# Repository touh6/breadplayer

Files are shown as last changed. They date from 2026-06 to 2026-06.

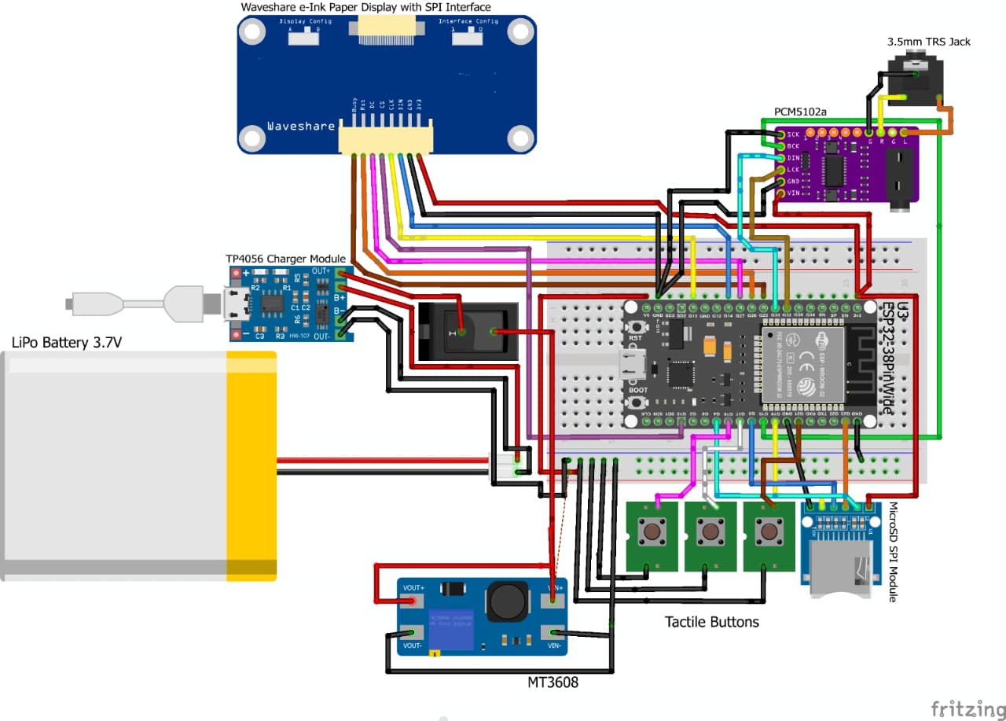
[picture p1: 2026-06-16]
images/wiring diagram.jpeg

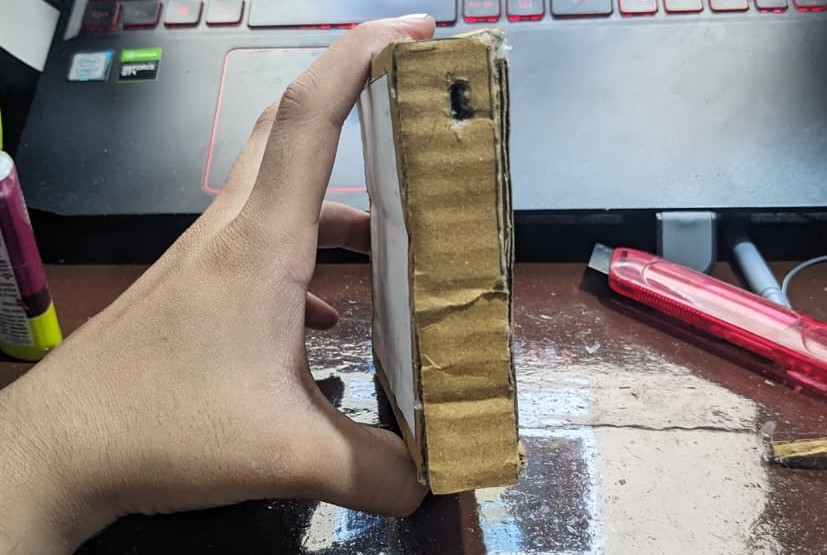
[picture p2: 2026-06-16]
images/left cbd.jpeg

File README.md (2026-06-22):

# breadplayer
full ds
a cassette player styled mp3 player with an e-ink display that shows album art when music is played.

## about the project:
this is an mp3 player with a 3d printed enclosure that is shaped like a cassette player. the heart of this device is the esp32-wroom microcontroller. other components include a waveshare 4.2'' e-Ink display, tactile buttons, pcm5102a, mt3608 booster, 3.5mm trs jack, microsd module with spi interface, tp4056 charging module, kcd11 spst switch and a 3.7v Li-Po battery. 

i wanted this to be in the shape of a cassette player as i've forever been enamored by retro tech. i absolutely love music; it is an integral part of me and i've always correlated them with my memories. so, this is special to me. 

i have a hard time visualizing certain things so i made a 2d version on canva to understand how i could actually pull this off and once i did, i made a dummy version of the same using cardboard. 

## 2d version:
<table><tr>
  <td></td>
    <td></td>
   <td></td>
    <td></td>
</tr></table>

## cardboard edition:
<table><tr>
  <td></td>
    <td></td>
   <td></td>
    <td></td>
</tr></table>

<table><tr>
  <td></td>
    <td></td>
   <td></td>
    <td></td>
</tr></table>

i was quite happy with how the dummy version turned out. i ended up sticking with the same visuals and designed the whole thing on solidworks.

## to build your own breadplayer: 
firstly, buy all the components as mentioned in the [bill of materials](https://github.com/touh6/breadplayer/tree/main/bill%20of%20materials), use the perfboard and solder them using the wiring diagram/schematic. and then, you will need to 3d print the enclosure { files of which you can find in the [cad folder](https://github.com/touh6/breadplayer/tree/main/cad) }, flash the microcontroller with [firmware](https://github.com/touh6/breadplayer/tree/main/firmware) using VS Code with PlatoformIO and then, assemble it all in the case and you're good to go! :))

## schematic:
v9
built using kicad

## wiring diagram:
WhatsApp Image 2026-06-16 at 3 24 42 PM
built using fritzing

## construction:
<table><tr>
  <td></td>
    <td></td>
</tr></table>

<table><tr>
      <h2 align="center">front & back: </h2>
  <td></td>
    <td></td>
</tr></table>

<table><tr>
      <h2 align="center">top view & side view: </h2>
   <td></td>
    <td></td>
</tr></table>

## assembled:
full 3

## tools i used:
<ul style="list-style-type:none;">
    <li>schematics: <a href="https://www.kicad.org">kicad</a></li>
    <li>cad: <a href="https://www.solidworks.com">solidworks</a></li>
    <li>wiring diagram: <a href="https://fritzing.org/">fritzing</a></li>
    <li>zine: <a href="https://www.canva.com">canva</a></li>
</ul>

## bill of materials: 
|name |quantity  |cost|link|
|---|---|---|-----|
|1) ESP32-WROOM-32 | 1|  $3.58 |[link](https://robu.in/product/esp-wroom-32-esp32-wifi-bt-ble-mcu-module/)|
|2) Waveshare 4.2'' e-Ink Paper Display Module With SPI Interface | 1|  $29.58 |[link](https://robu.in/product/4-2-inch-e-ink-paper-display-module-with-spi-interface/)|
|3)  PCM5102a DAC Decoder Module | 1|  $4.74 |[link](https://hubtronics.in/pcm5102-i2s-digital-audio-dac-decoder-module)|
|4) 3.5mm TRS jack | 1|  $0.10 |[link](https://hubtronics.in/3.5mm-4pole-audio-plug)|
|5) 3.3V MicroSD SPI Module| 1|  $0.46 |[link](https://robocraze.com/products/sd-card-module)|
|6) Tactile Buttons| 10|  $0.47 |[link](https://robu.in/product/12x12x12mm-tactile-push-button-switch-10pcs/)|
|7) 3.7v Li-Po Battery (WLY803040) | 1|  $3.98 |[link](https://robu.in/product/wly803040-1000mah-3-7v-single-cell-rechargeable-lipo-battery/)|
|8) TP4056 Charging Module| 1|  $0.13  |[link](https://robu.in/product/tp4056-1a-li-ion-lithium-battery-charging-module-with-current-protection-type-c/)|
|9) KCD11 SPST Switch| 1|  $0.15 |[link](https://probots.co.in/rocker-switch-mini-on-off-spst-2-pin-kcd11.html)|
|10) MT3608 Booster| 1|  $0.34 |[link](https://robu.in/product/mt3608-2a-max-dc-dc-step-up-power-module-booster-power-module/)|
|10) Perfboard| 4|  $1.05 |[link](https://probots.co.in/dot-pcb-perfboard.html)|
|10) 3D Printing| 4|  $10 |[link](https:/)|
|shipping  | | $3.17 | |
| | total  |$57.75 |  |  |

as of 16th june 2026

## zine:
breadplayer

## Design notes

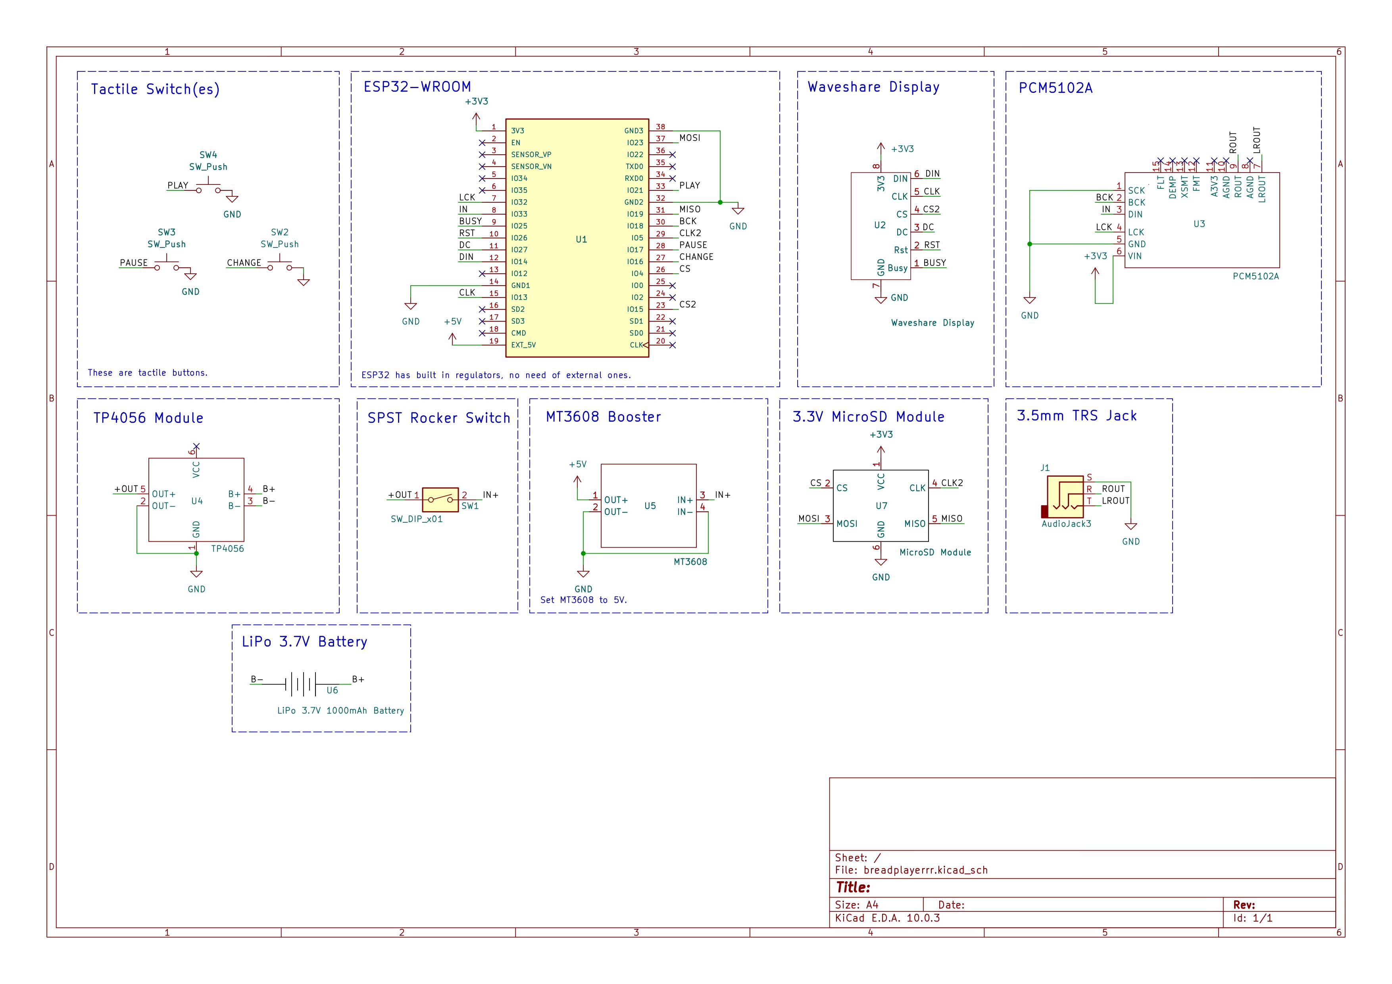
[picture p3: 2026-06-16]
images/schematic.jpg

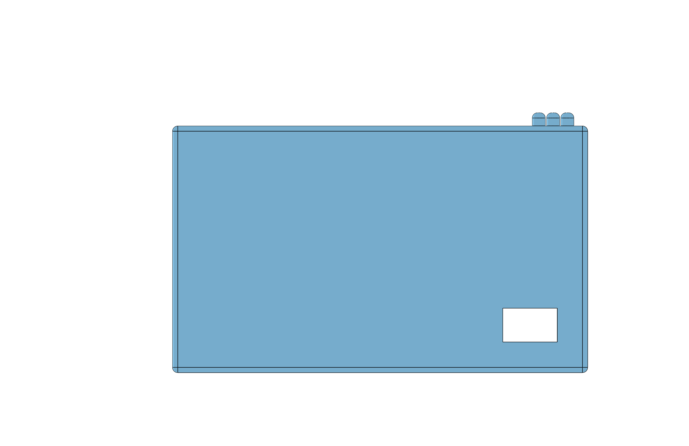
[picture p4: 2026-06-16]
images/back.PNG

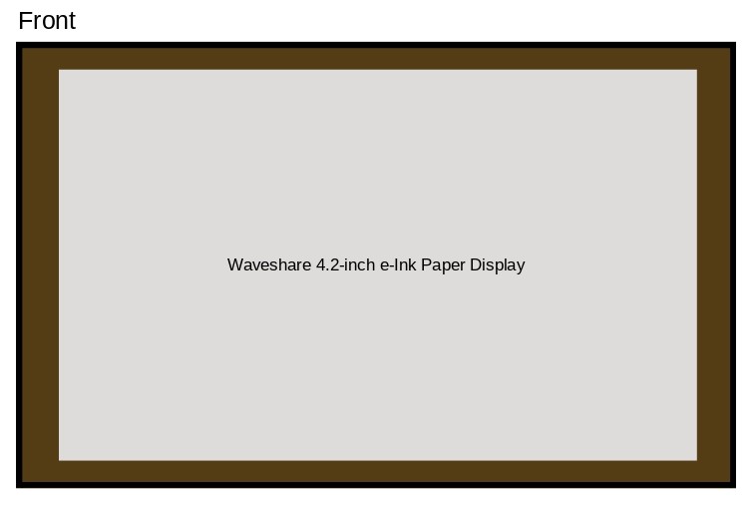
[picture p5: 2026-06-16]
images/front-2d.jpg

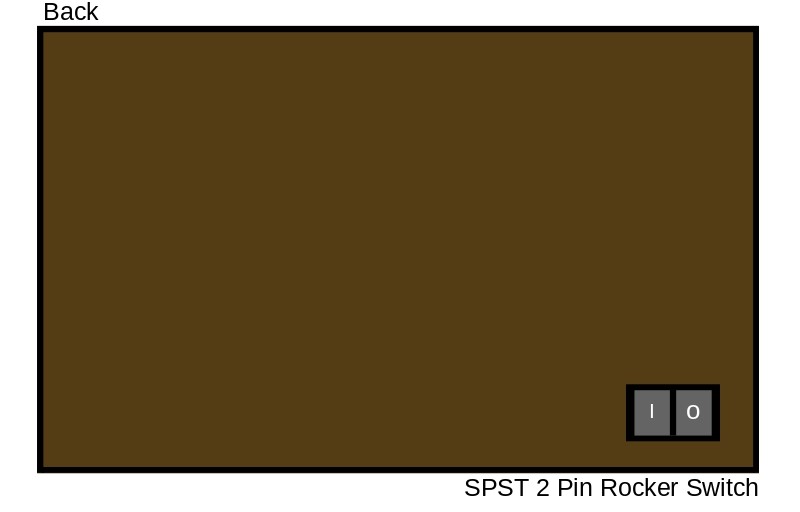
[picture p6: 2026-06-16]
images/back-2d.jpg

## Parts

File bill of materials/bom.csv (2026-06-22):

name | quantity | cost | link
ESP32-WROOM-32 | 1 | 3.58 | https://robu.in/product/esp-wroom-32-esp32-wifi-bt-ble-mcu-module/
Waveshare 4.2'' e-Ink Paper Display Module With SPI Interface | 1 | 29.58 | https://robu.in/product/4-2-inch-e-ink-paper-display-module-with-spi-interface/
PCM5102a DAC Decoder Module | 1 | 4.74 | https://hubtronics.in/pcm5102-i2s-digital-audio-dac-decoder-module
3.5mm TRS jack | 1 | 0.1 | https://hubtronics.in/3.5mm-4pole-audio-plug
3.3V MicroSD SPI Module | 1 | 0.46 | https://robocraze.com/products/sd-card-module
Tactile Buttons | 10 | 0.47 | https://robu.in/product/12x12x12mm-tactile-push-button-switch-10pcs/
3.7v Li-Po Battery (WLY803040) | 1 | 3.98 | https://robu.in/product/wly803040-1000mah-3-7v-single-cell-rechargeable-lipo-battery/
TP4056 Charging Module | 1 | 0.13 | https://robu.in/product/tp4056-1a-li-ion-lithium-battery-charging-module-with-current-protection-type-c/
MT3608 Booster | 1 | 0.34 | https://robu.in/product/mt3608-2a-max-dc-dc-step-up-power-module-booster-power-module/
Perfboard | 4 | 1.05 | https://probots.co.in/dot-pcb-perfboard.html
3D Printing | 5 | 10 | https:
shipping |  | 3.17
 | total | 47.75

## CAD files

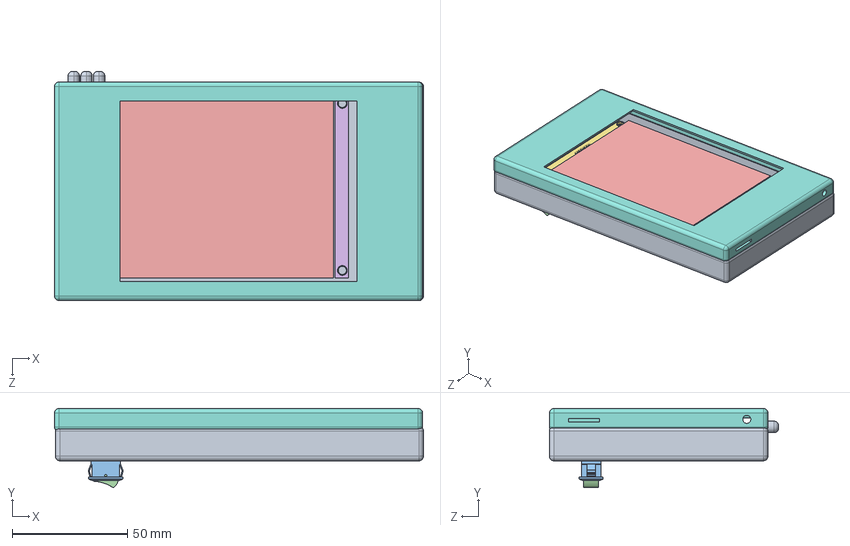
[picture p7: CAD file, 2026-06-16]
cad/assembled.STEP
160.4 x 34.3 x 99.7 mm
back s
pin001_1.step x 2
Corps001_1.step
bouton001_1.step
display
front s
buttons

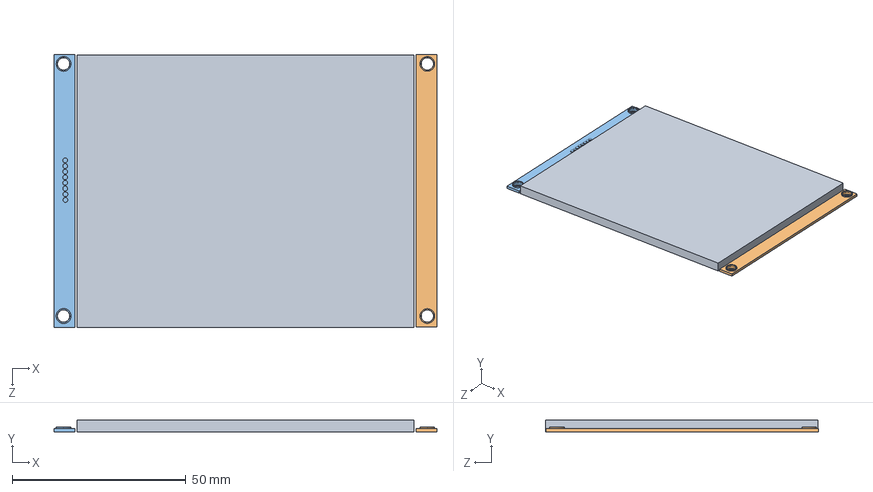
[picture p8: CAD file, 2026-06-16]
cad/display.STEP
110.2 x 3.50 x 78.6 mm

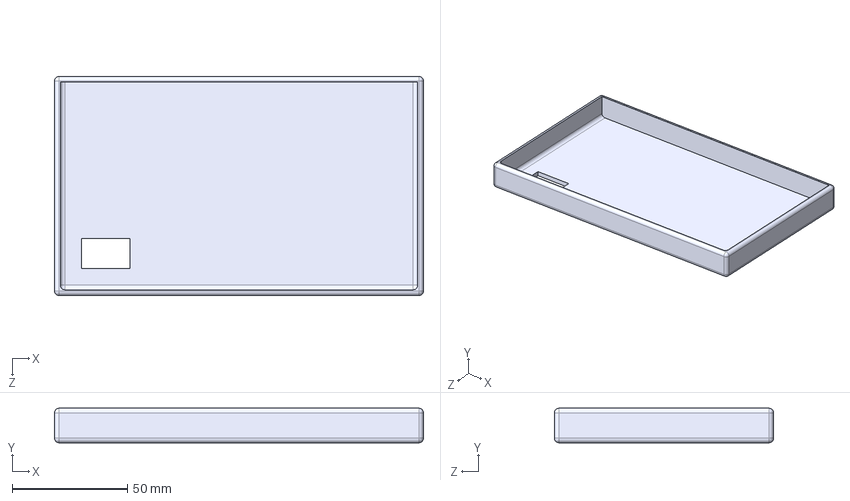
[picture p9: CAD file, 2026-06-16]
cad/back s.STEP
160.0 x 15.0 x 95.0 mm

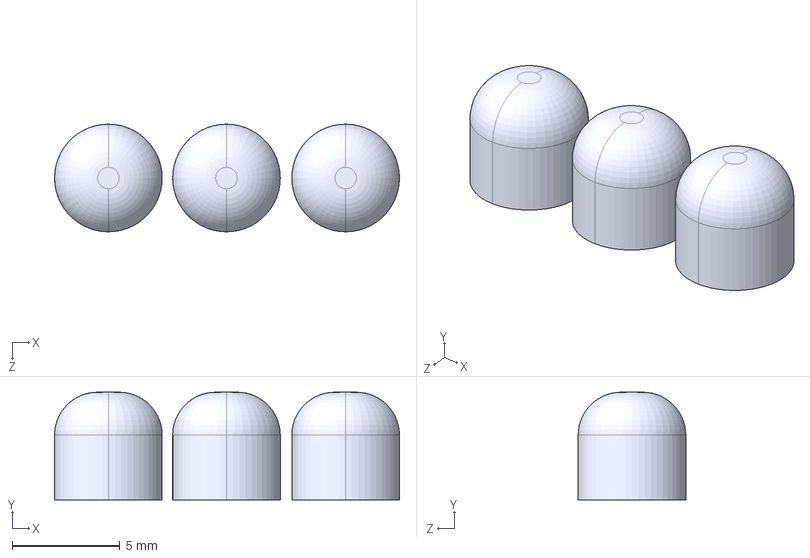
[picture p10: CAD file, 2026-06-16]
cad/buttons.STEP
16.0 x 5.00 x 5.00 mm

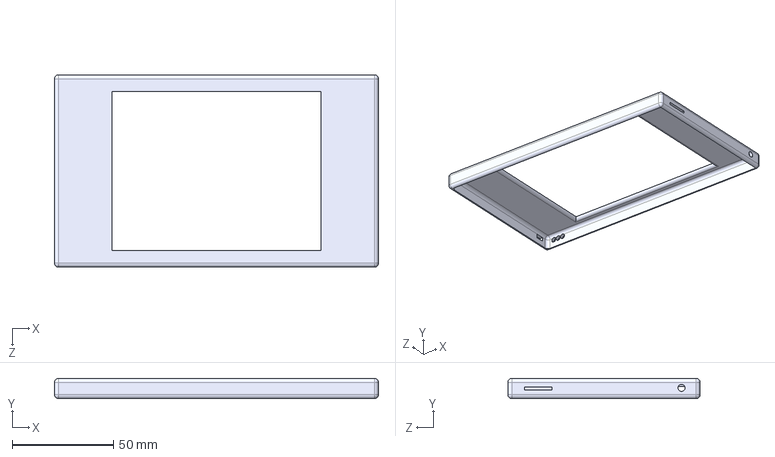
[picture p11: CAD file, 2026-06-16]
cad/front s.STEP
160.0 x 10.0 x 95.0 mm

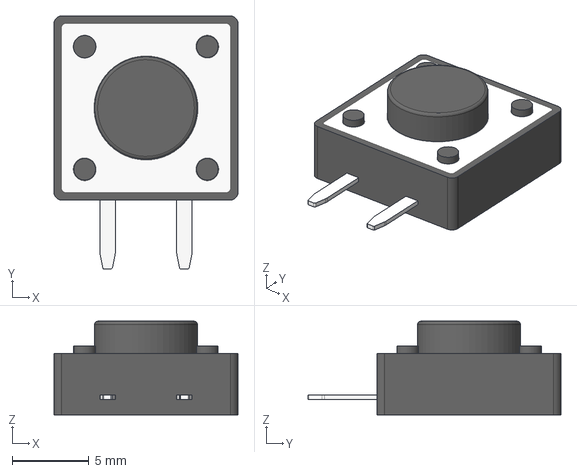
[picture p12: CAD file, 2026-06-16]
cad/Taster 12x12mm-Extrude004.step
12.0 x 16.5 x 6.10 mm

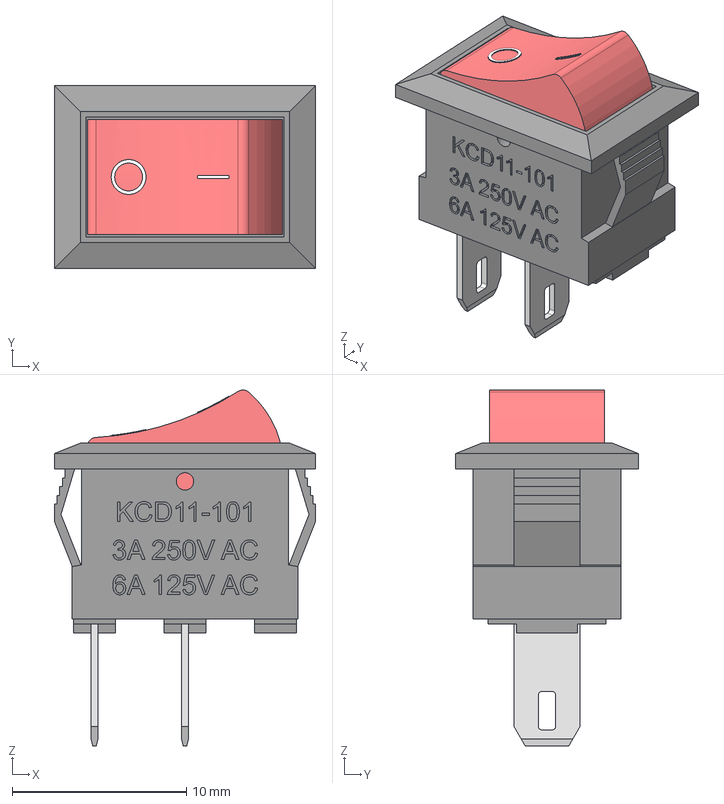
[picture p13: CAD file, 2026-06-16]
cad/small_MA_switch_b.step
15.0 x 10.5 x 20.4 mm
pin001 x 2
Corps001
bouton001

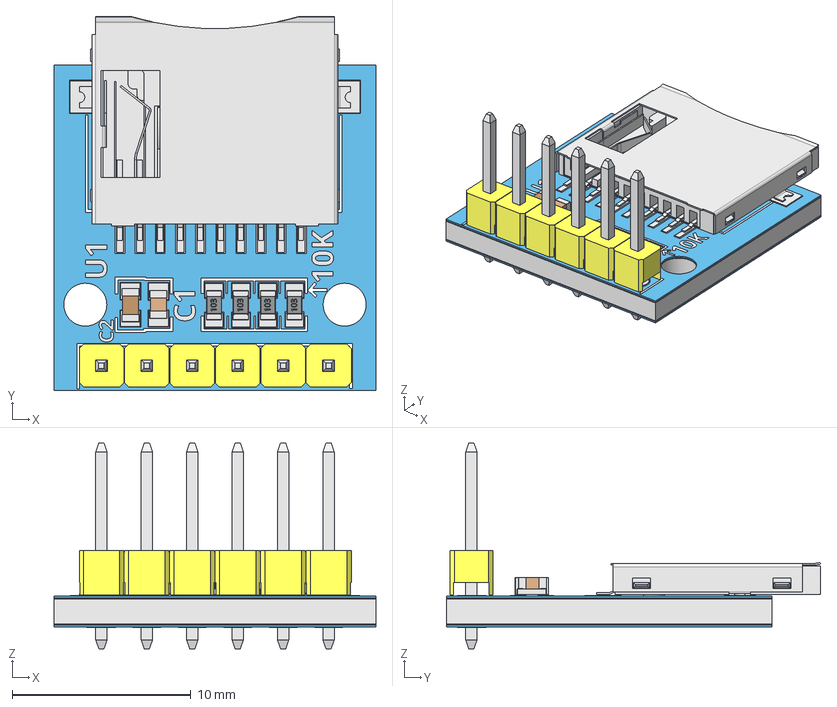
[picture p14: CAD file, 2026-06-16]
cad/microSD_module_pls.step
18.0 x 20.9 x 11.5 mm
board_body
mask_up
mask_bt
metal_bt
metal_up
silk001
silk002
silk003
silk004
silk005
silk007
silk008
10K
U1
C1
C2
3V3
CS
MOSI
CLK001
MISO
GND001
sd_cover
conn001
conn002
conn003
conn004
conn005
conn006
conn007
conn008
conn009
conn010
pin011
label006
ShapeString009
pin012
pin013
label007
ShapeString010
pin014
pin015
label008
ShapeString011
pin016
pin017
label009
ShapeString012
pin018
contact019
contact020
contact033
contact034
Frame
Pin001
Pin002
Pin003
Pin004
Pin011
Pin012

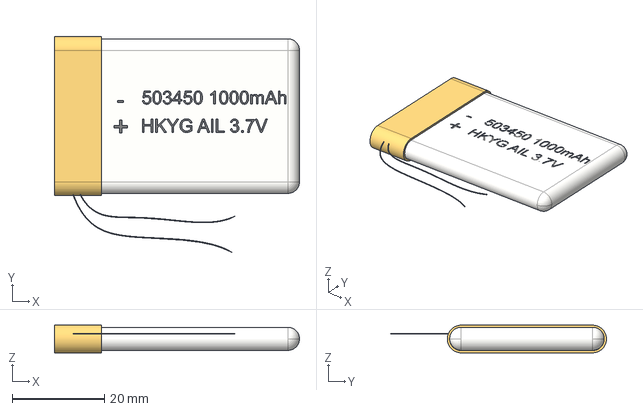
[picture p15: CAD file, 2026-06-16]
cad/Bateria LiPo 3.7V 1000mA 503450 v23.step
53.1 x 46.8 x 6.00 mm

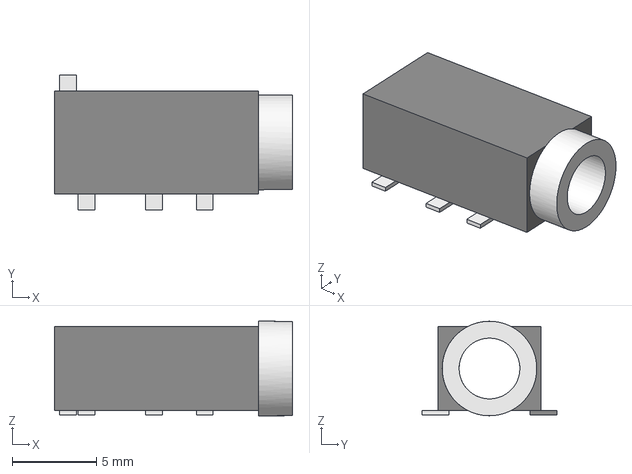
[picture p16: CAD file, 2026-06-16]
cad/TRRS20153.step
14.1 x 8.00 x 5.60 mm

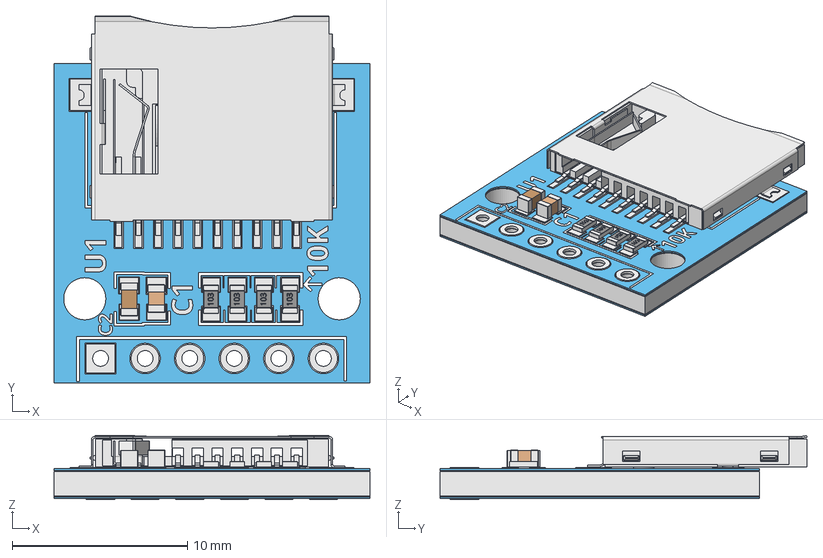
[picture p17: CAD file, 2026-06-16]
cad/microSD_module.step
18.0 x 20.9 x 3.65 mm
board_body
mask_up
mask_bt
metal_bt
metal_up
silk001
silk002
silk003
silk004
silk005
silk007
silk008
10K
U1
C1
C2
3V3
CS
MOSI
CLK001
MISO
GND001
sd_cover
conn001
conn002
conn003
conn004
conn005
conn006
conn007
conn008
conn009
conn010
pin011
label006
ShapeString009
pin012
pin013
label007
ShapeString010
pin014
pin015
label008
ShapeString011
pin016
pin017
label009
ShapeString012
pin018
contact019
contact020
contact033
contact034

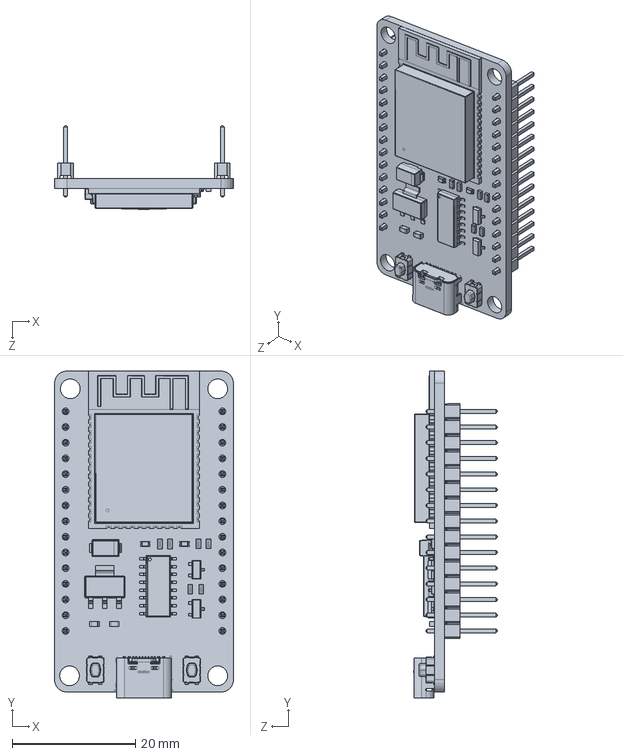
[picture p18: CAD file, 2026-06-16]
cad/esp32_30pin.SLDPRT
29.0 x 53.0 x 13.5 mm

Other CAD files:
cad/MT3608 Converter.x_t
cad/assembled.SLDASM
cad/back s.SLDPRT
cad/buttons.SLDPRT
cad/display.SLDPRT
cad/front s.SLDPRT

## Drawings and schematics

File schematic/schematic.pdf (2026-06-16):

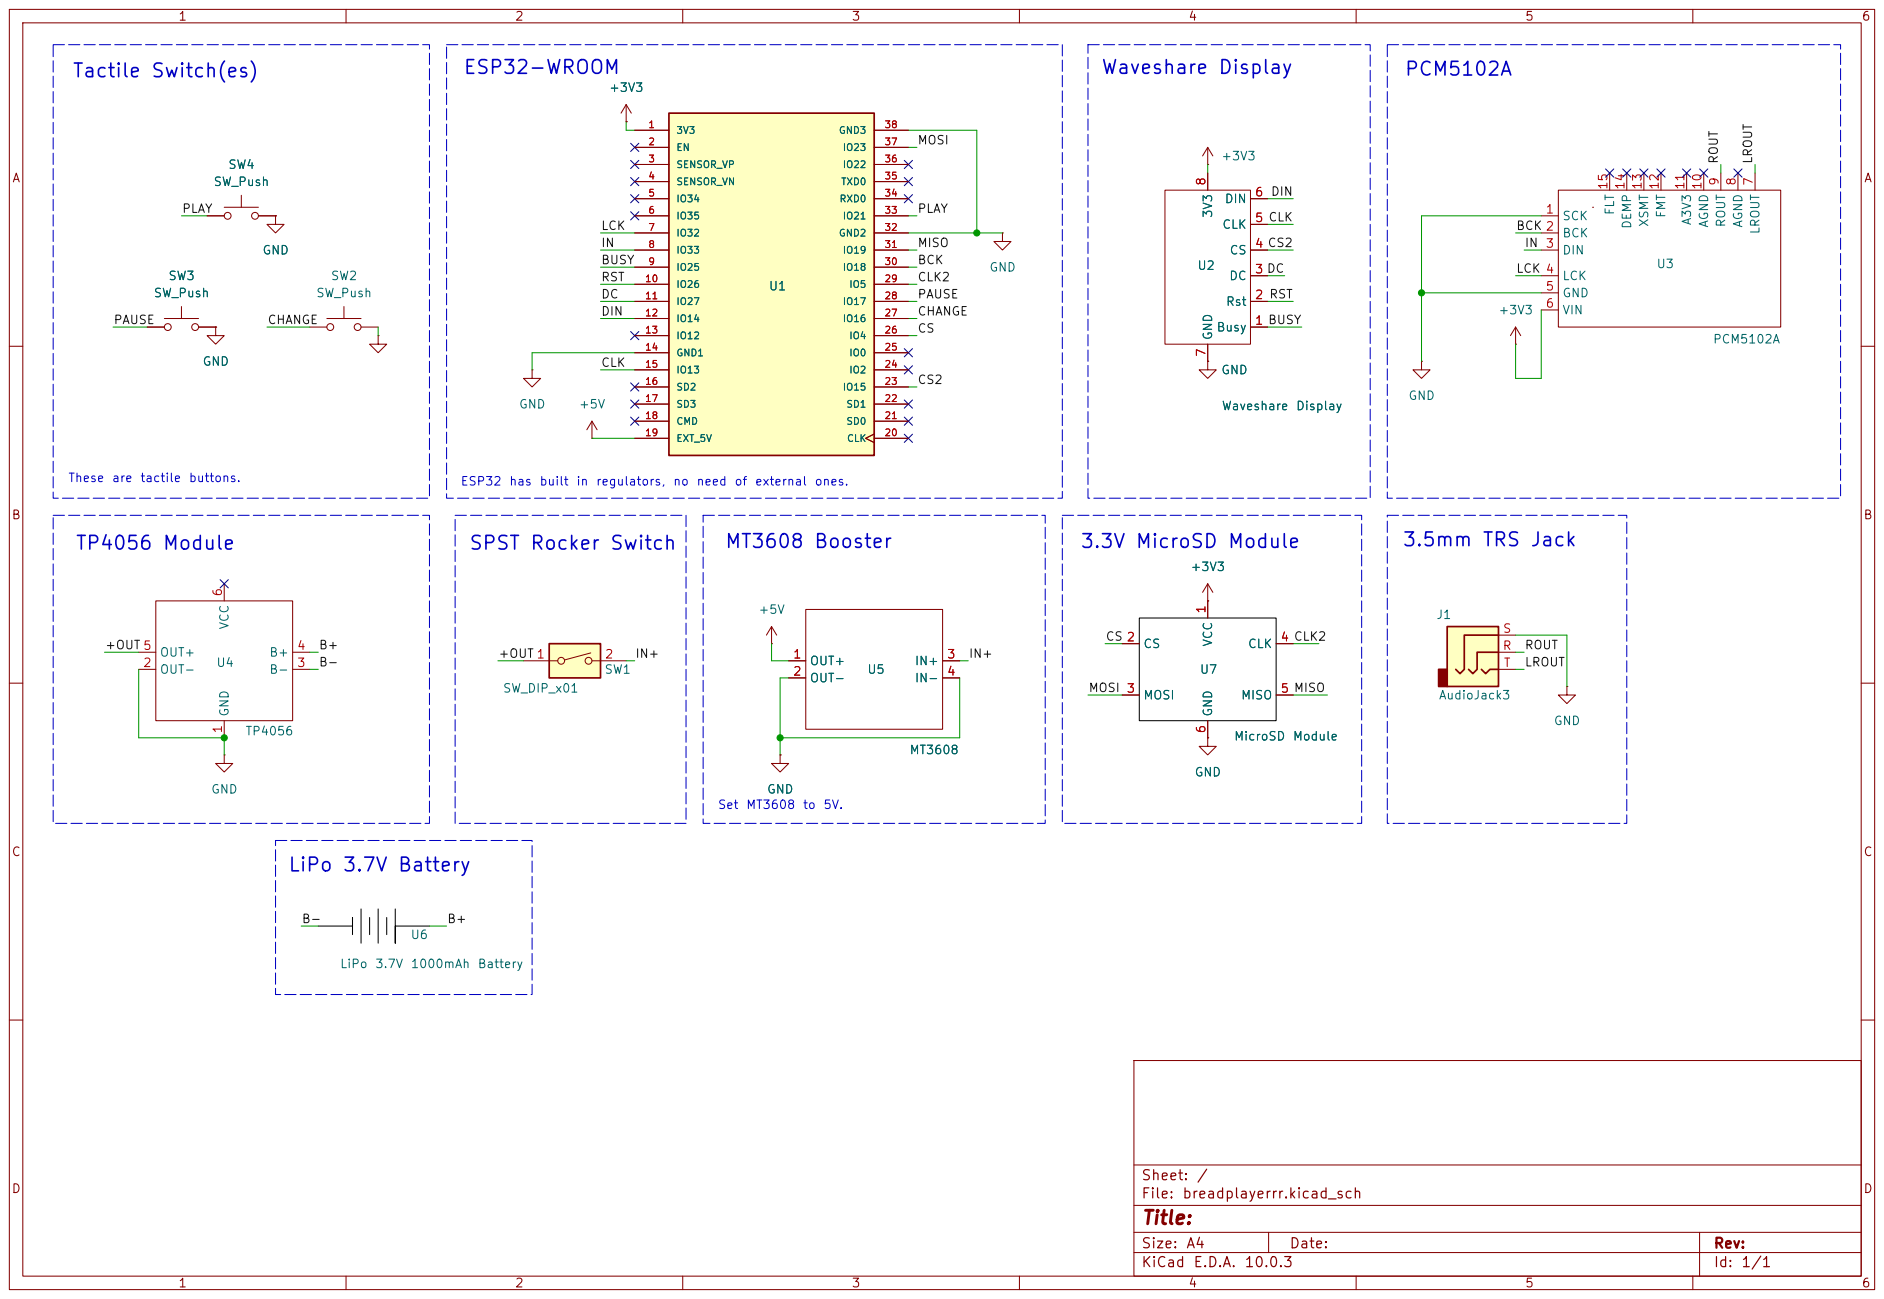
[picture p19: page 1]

8 U2 GND Waveshare Display +3V3 GND +5V GND

8 ROUT 9 AGND 10 A3V3 11 FMT 12 XSMT 13 DEMP 14 FLT 15 U3 PCM5102A GND

1 CS 2 MOSI 3 CLK 4 MISO 5 GND

Size: A4 | Rev:
KiCad E.D.A. 10.0.3 | Id: 1/1

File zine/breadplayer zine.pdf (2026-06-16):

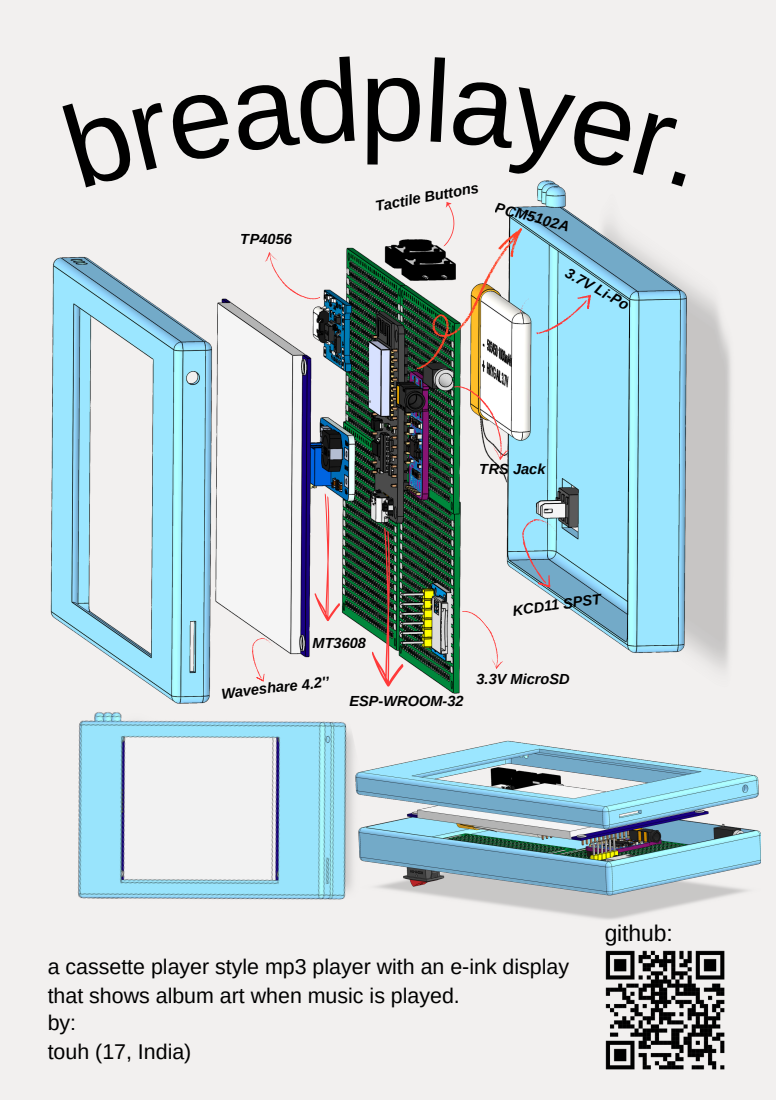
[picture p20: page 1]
breadplayer.; github:

Tactile Buttons Waveshare 4.2'’ ESP-WROOM-32 3.3V MicroSD KCD11 SPST TRS Jack PCM5102A

a cassette player style mp3 player with an e-ink display
that shows album art when music is played.
touh (17, India)

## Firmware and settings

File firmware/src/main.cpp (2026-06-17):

#include <Arudino.h>

#include "storage.h"
#include "audio.h"
#include "display.h"
#include "buttons.h"
#include "battery.h"

void setup()
{

Serial.begin(
115200
);

storageBegin();

scanMusic();

displayBegin();

audioBegin();

buttonsBegin();

if(
  getSongs()>0
  )
{

playCurrentSong();

updateScreen(

getCurrentSong(),

getCurrentArt(),

batteryPercent(),

0

  );

}

void loop()
{

audioLoop();

checkButtons();

static unsigned long t=0;

if(
  millis()-t > 30000
  )
{

updateScreen(

getCurrentSong(),

getCurrentArt(),

batteryPercent(),

getElapsed()

);

t=millis();

}


}

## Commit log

2026-06-16 Create bill of materials
2026-06-16 Create schematic (kicad)
